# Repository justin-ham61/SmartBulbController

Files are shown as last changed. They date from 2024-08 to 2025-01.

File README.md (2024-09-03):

# SmartBulbController
SmartBulbController is an open-source input device built for the ESP32 microcontroller for controlling Smart Bulbs using the TP-Link Smart Home Protocol.

The goal of this project was to create a remote control device for Kasa Smart Lighting system within local network in order to eliminate the need for a smart phone app for lighting control.

# Dependencies
Several libraries are required for the device to work. 
- Adafruit_SSD1306 by Adafruit
- Adafruit_BusIO by Adafruit
- Adafruit_GFX_Library by Adafruit
- Ai_Esp32_Rotary_Encoder by Igor Antolic
- KasaSmartPlug updated by Justin Ham
    - Modified version of the [KasaSmartPlug](https://github.com/kj831ca/KasaSmartPlug?tab=readme-ov-file) library by Kris Jearakul to be compatible with Smart Bulbs and Smart Plugs.
- ArduinoJson by Benoit Blanchon

# Features
- Quick communication with light bulbs using the TP-Link Smart Home Protocol which is a TCP/IP Protocol that sends JSON payloads to devices. 
- Rotary Knob allows the control of brightness for multiple bulbs at the same time which is not available in the Kasa app.
- Built on FreeRTOS for efficient and responsive device interaction.
- OLED Display for bulb management and view of device states such as (On, Off, Error).

# FreeRTOS
- WiFi related tasks are managed using Semaphores and prohibits reliant tasks from running unless a connection is successfully made.
- User inputs are handled with ISR's that interact with RTOS queues.
- All tasks only operate when items are added to the queue and executes them promptly.
- Tasks notify lower priority tasks such as display task in order to update display.

# Designs

## Device Render
Device was designed with Fusion and prototype was printed using an Ender 3 Pro 3D Printer.

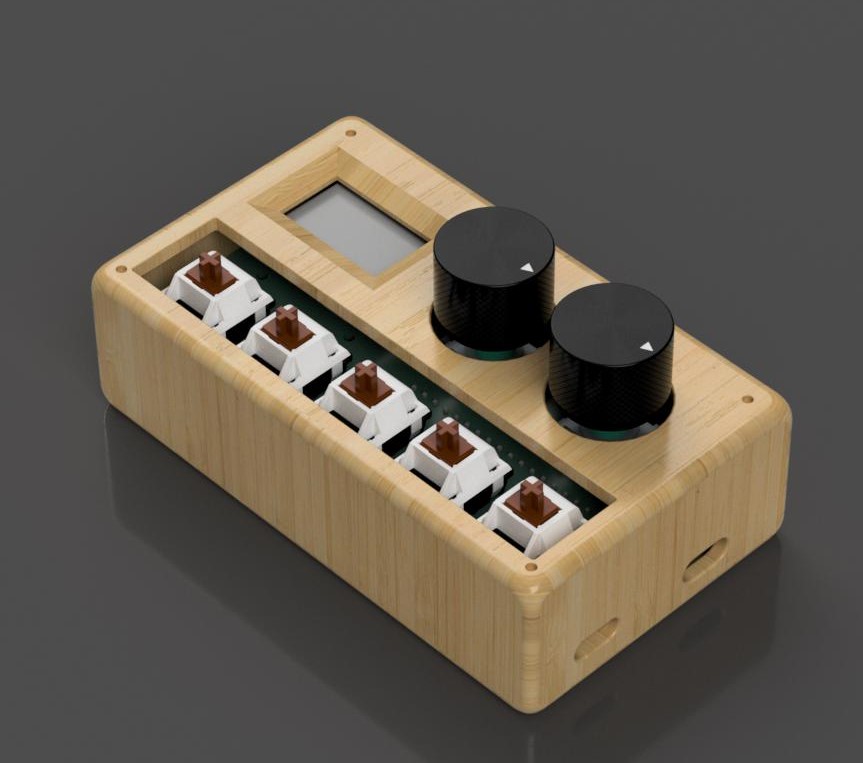
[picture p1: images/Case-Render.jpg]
Device Render


## First Working Prototype
First working prototype of the controller with a custom PCB and the 3D printed case.

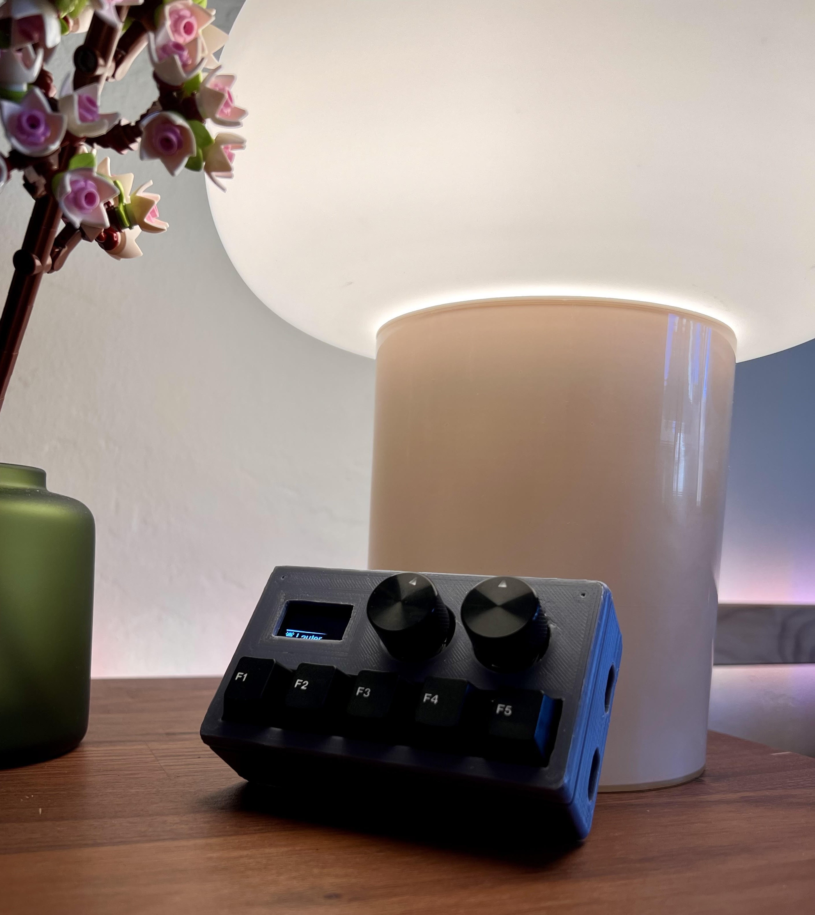
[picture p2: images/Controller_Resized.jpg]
Prototype Image


## OLED Display
- Menu
    - List of all bulbs and a dedicated "Reset" command for the ESP32 microcontroller. 
        - Although the firmware has auto update for dynamic IP assignment, it may have issue updating to the most recent IP address of the bulb.
        - The reset button can be used to restart the device and connect to the new IP.
- Bulbs show the current state of the bulb 
    - On
    - Off
    - Error (Exclamation icon)
- Changing the brightness will show the current brightness as a progress bar.

## Inputs
- 2 Rotary Encoders
    - 1 Encoder for menu navigation
    - 1 Encoder for On/Off and brightness control
- 5 Switches (MX Style)
    - Quick toggle for individual bulbs
    
## Control Options
User can control their light bulbs in several different ways

1. Use the quick use rotary encoder
    - Press encoder button to toggle On/Off for all bulbs
    - Rotate encoder knob to change the brightness for all bulbs
2. Quck individual bulb toggle
    - The 5 switches allow the users to quickly turn on and off individual bulbs
3. Menu Select toggle
    - Navigate and select desired bulb on the menu in order to toggle and change the brightness of a specific bulb.  

# Set Up Guide

1. Gather all materials listed in the parts document, you can order the PCB using the provided files or wire the device with a breadboard following the schematics. 
2. Prepare config file before flashing the device (Instruction shown below).
3. Once the device is put together, flash the device with the firmware and required libraries using the Arduino IDE.
4. Device set up will run automatically on initial start up. 
    - This step includes the device searching for bulbs as outlined in the config file on the local wifi network.
    - Having the device connected to a computer and reading the Serial output will help with any connectivity issues. 
    - Notes about better connection below
5. Once set up, all lightbulbs named in the config file should show up on the main menu.
6. The first 5 lights can be toggled with the 5 switches.

## Config File Instruction
In order to flash the ESP32 module with the firmware, the user must update the config file with some information.
- Home Wifi SSID (name) and Password
- Names of all light bulbs they want
    - Name must match the name set for the bulb during set up exactly.
- Total number of bulbs
~~~c++
#ifndef CONFIG_H
#define CONFIG_H

const char* SSID = "<User WiFi SSID>";
const char* PASSWORD = "<User WiFi Password>";

//List of all user bulb names
char* aliases[] = {
  "<User Bulb Name 1>",
  "<User Bulb Name 2>",
  "<User Bulb Name 3>"
};

//Total number of bulbs, needs to match the number of bulb names above.
const int size = 0;

//Time between inactivity and sleep
const int inactivity_time = 15000;

//Minimum and Maximum brightness
const int min_brightness = 0;
const int max_brightness = 100;

#endif
~~~~

On start up, the ESP32 will begin to look for bulbs that are active and add them to the device's list of bulbs if the name is included in the config file.

For best results, please turn the smart bulb on with a phone during the set up.

# Future Plans
- Light temperature and color control.
- Custom group creations to group certain bulbs with another.
- Better rotary knob control between menu and controlling bulbs.
- Compatibility with devices that require Kasa Authentication such as light strips.

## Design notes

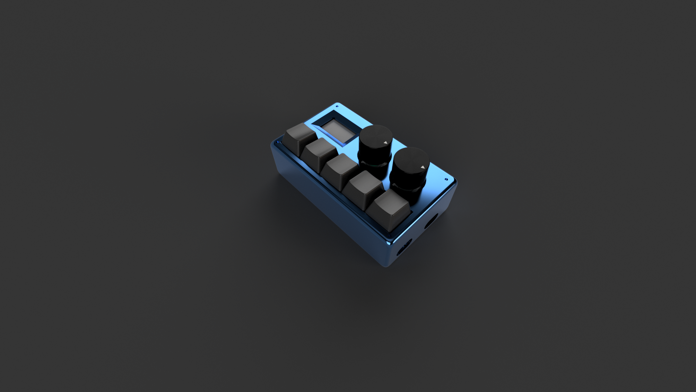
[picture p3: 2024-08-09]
images/Case.png

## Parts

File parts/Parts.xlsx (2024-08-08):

ESP32 | https://www.amazon.com/dp/B0718T232Z?psc=1&ref=ppx_yo2ov_dt_b_product_details
128 x 64 .96 Inch OLED Screen | https://www.amazon.com/dp/B0D46JPZHZ?psc=1&ref=ppx_yo2ov_dt_b_product_details
MX Style Switches | https://divinikey.com/products/cherry-mx2a-black-linear-switches?variant=41617139499073
EC11 Rotary Encoder | https://www.amazon.com/DIYhz-Rotary-Encoder-Digital-Potentiometer/dp/B07D3DF8TK
Rechargeable Lithium Battery | https://www.amazon.com/dp/B07CXNQ3ZR?psc=1&ref=ppx_yo2ov_dt_b_product_details
Charging Module (T4056) | https://www.amazon.com/dp/B07PKND8KG?psc=1&ref=ppx_yo2ov_dt_b_product_details
JST Cables | https://www.amazon.com/dp/B013JRWCBU?psc=1&ref=ppx_yo2ov_dt_b_product_details

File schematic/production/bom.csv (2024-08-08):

Designator | Footprint | Quantity | Value | LCSC Part #
R1, R2, R3, R4, R5, R6, R7 | 1206 | 7 | R_Small_US

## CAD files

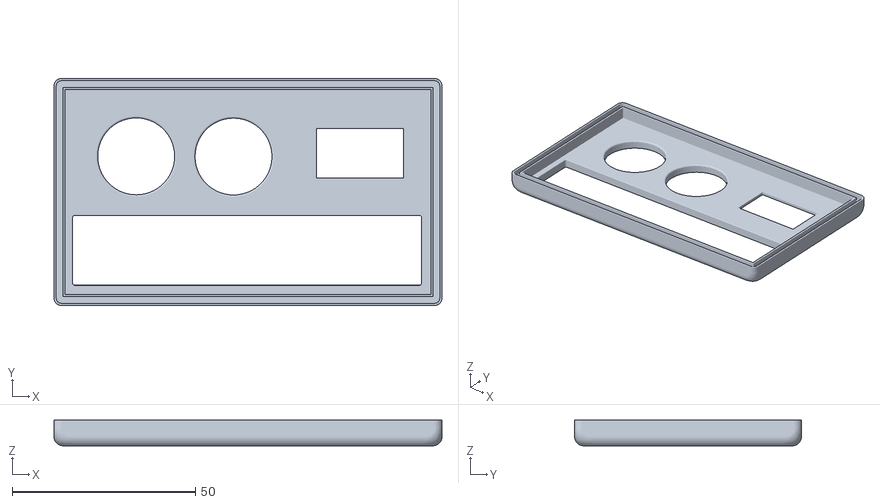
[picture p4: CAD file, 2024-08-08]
cad/Top.stl
106.0 x 62.0 x 7.00

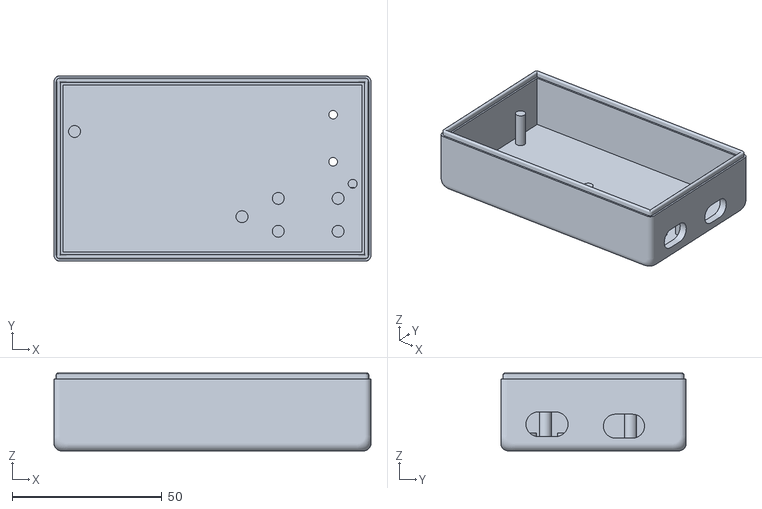
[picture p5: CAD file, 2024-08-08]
cad/Bottom.stl
106.0 x 62.0 x 26.0

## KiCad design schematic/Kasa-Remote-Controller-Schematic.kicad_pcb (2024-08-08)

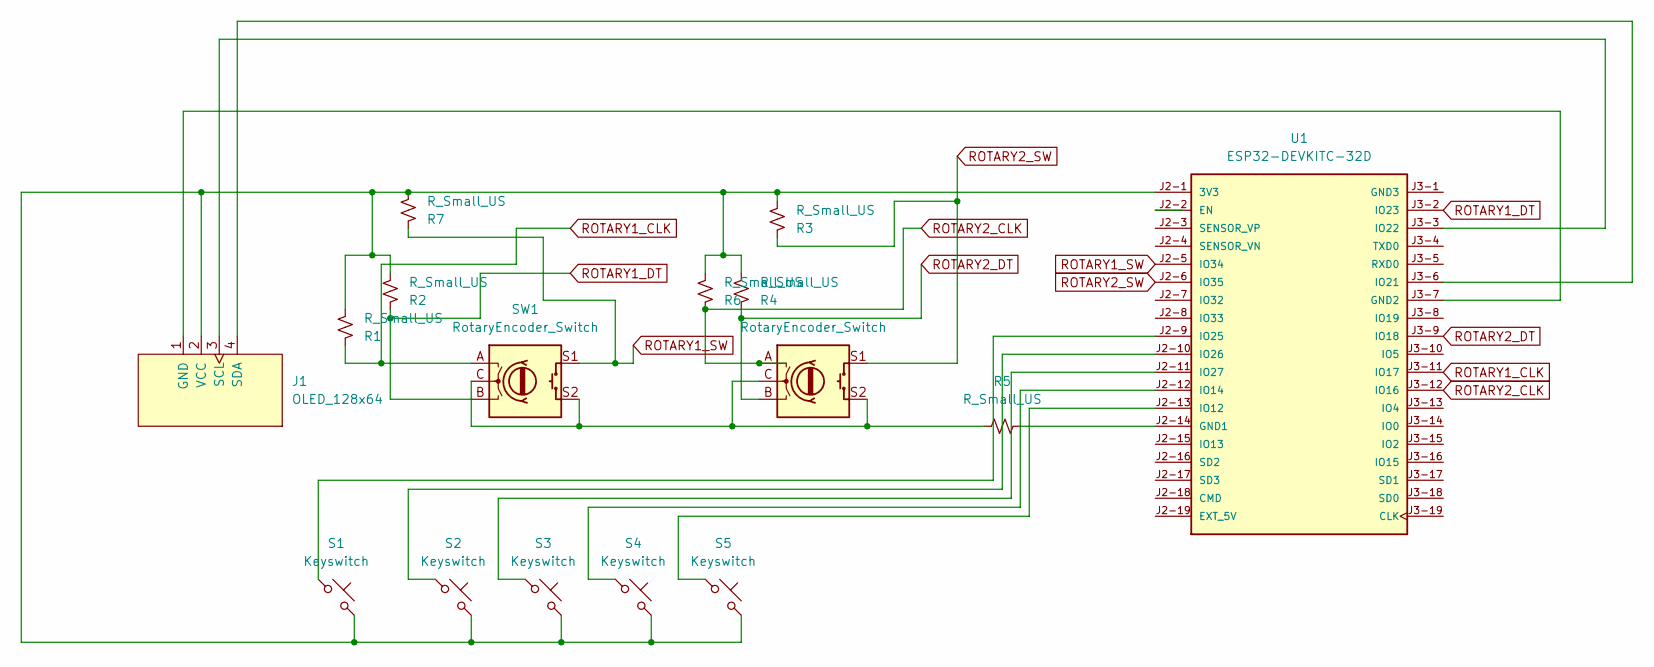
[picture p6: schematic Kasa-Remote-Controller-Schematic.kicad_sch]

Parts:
J1: OLED_128x64; MODULE_DM-OLED096-636
R1, R2, R3, R4, R5, R6, R7: R_Small_US; R_1206_3216Metric_Pad1.30x1.75mm_HandSolder
S1, S2, S3, S4, S5: Keyswitch; MX_PCB_1.00u
SW1, SW2: RotaryEncoder_Switch; RotaryEncoder_Alps_EC12E-Switch_Vertical_H20mm
U1: ESP32-DEVKITC-32D; MODULE_ESP32-DEVKITC-32D; PARTREV V4

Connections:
unnamed: J1.1 (GND), U1.J3-7 (GND2)
unnamed: J1.3 (SCL), U1.J3-3 (IO22)
unnamed: J1.4 (SDA), U1.J3-6 (IO21)
unnamed: J1.2 (VCC), R1.2, R2.2, R3.2, R4.2, R6.2, R7.2, S1.2, S2.2, S3.2, S4.2, S5.2, U1.J2-1 (3V3)
unnamed: R5.1, SW1.C, SW1.S2, SW2.C, SW2.S2
unnamed: R5.2, U1.J2-14 (GND1)
unnamed: S5.1, U1.J2-13 (IO12)
unnamed: S4.1, U1.J2-12 (IO14)
unnamed: S1.1, U1.J2-9 (IO25)
unnamed: S2.1, U1.J2-10 (IO26)
unnamed: S3.1, U1.J2-11 (IO27)
ROTARY1_CLK: R1.1, SW1.A, U1.J3-11 (IO17)
ROTARY1_DT: R2.1, SW1.B, U1.J3-2 (IO23)
ROTARY1_SW: R7.1, SW1.S1, U1.J2-5 (IO34)
ROTARY2_CLK: R6.1, SW2.A, U1.J3-12 (IO16)
ROTARY2_DT: R4.1, SW2.B, U1.J3-9 (IO18)
ROTARY2_SW: R3.1, SW2.S1, U1.J2-6 (IO35)

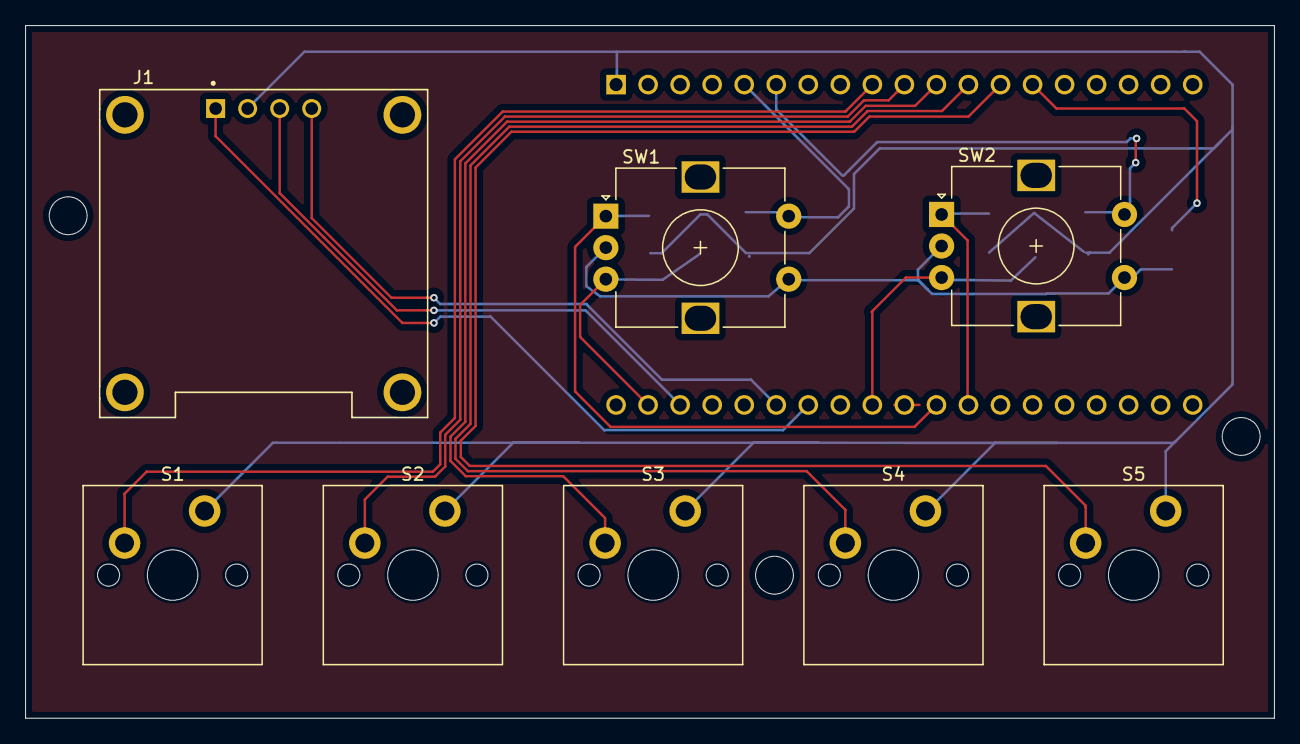
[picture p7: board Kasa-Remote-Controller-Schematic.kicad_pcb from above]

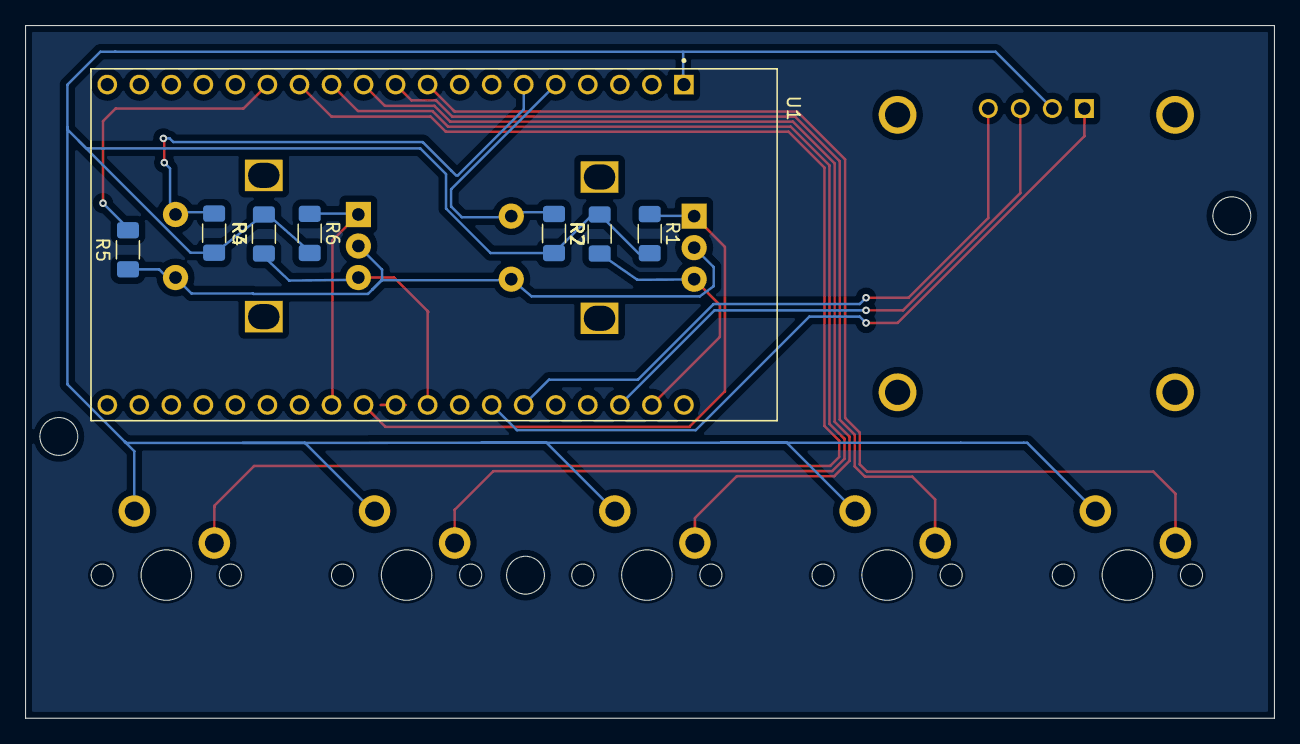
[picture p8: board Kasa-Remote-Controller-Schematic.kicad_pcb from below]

Board: 2 copper layers, 99.0 x 54.9 mm, 16 parts (8 on the bottom side), 17 nets.

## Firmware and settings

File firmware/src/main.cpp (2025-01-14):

#include <stdio.h>
#include "Arduino.h"
#include <WiFi.h>
#include "freertos/FreeRTOS.h"
#include "freertos/task.h"
#include "freertos/timers.h"
#include "driver/gpio.h"
#include "config.h"
#include "esp_sleep.h"
#include "typedef/command.h"
#include "typedef/menu_item.h"

#include "task_device_setup/task_device_setup.h"
#include "task_update_flash/task_update_flash.h"
#include "task_display/task_display.h"
#include "task_command/task_command.h"

// ------------------- Libraries ------------------------ //
#include <ArduinoJson.h>
#include <AiEsp32RotaryEncoder.h>
#include <AiEsp32RotaryEncoderNumberSelector.h>
#include <KasaSmartPlug.h>
#include <Adafruit_GFX.h>
#include <Adafruit_SSD1306.h>
#include <Wire.h>
#include <Fonts/FreeSans9pt7b.h>
#include <Fonts/FreeSansBold9pt7b.h>
#include <EEPROM.h>

#if CONFIG_FREERTOS_UNICORE
static const BaseType_t app_cpu = 0;
#else 
static const BaseType_t app_cpu = 1;
#endif

//Pin Set up
#include "pin_def.h"

AiEsp32RotaryEncoder *quick_rotary_encoder = new AiEsp32RotaryEncoder(QUICK_ROTARY_DT, QUICK_ROTARY_CLK, QUICK_ROTARY_SW, VCC_PIN, ROTARY_ENCODER_STEPS);
AiEsp32RotaryEncoderNumberSelector quick_number_selector = AiEsp32RotaryEncoderNumberSelector();
AiEsp32RotaryEncoder menu_rotary_encoder = AiEsp32RotaryEncoder(MENU_ROTARY_DT, MENU_ROTARY_CLK, MENU_ROTARY_SW, VCC_PIN, ROTARY_ENCODER_STEPS);

//Queue Set up
static const uint8_t max_command_queue_len = 10;
QueueHandle_t command_queue;

static const uint8_t max_toggle_queue_len = 5;
QueueHandle_t toggle_queue;

static const uint8_t max_brightness_queue_len = 5;
QueueHandle_t brightness_queue;

static const uint8_t max_color_queue_len = 5;
QueueHandle_t color_queue;


static const uint8_t max_menu_display_queue_len = 5;
static QueueHandle_t menu_display_queue;

//Debounce and Button Queue Timers
TimerHandle_t xTimer;
TimerHandle_t xQuickRotaryTimer;
TimerHandle_t xModeSwitchTimer;
TimerHandle_t xMenuRotarySwitchTimer;
TimerHandle_t xQuickRotarySwitchTimer;

//Button Flag
volatile uint8_t button_state_flag;


//Task Handles
static TaskHandle_t command_read_task_handle = NULL;
TaskHandle_t display_task_handle = NULL;
static TaskHandle_t wifi_task_handle = NULL;
static TaskHandle_t device_discover_task_handle = NULL;
static TaskHandle_t toggle_bulb_task_handle = NULL;
static TaskHandle_t quick_rotary_task_handle = NULL;
static TaskHandle_t brightness_task_handle = NULL;
static TaskHandle_t menu_rotary_task_handle = NULL;
static TaskHandle_t brightness_display_task_handle = NULL;
static TaskHandle_t color_task_handle = NULL;
static TaskHandle_t update_flash_task_handle = NULL;

//Sleep Handles
TimerHandle_t xIdleTimer;
esp_sleep_source_t wakeup_source; 

//Wifi Dependancies
SemaphoreHandle_t wifiSemaphore;

//Bulbs
KASAUtil kasaUtil;

int numberOfBulbs;
bool all_state = false;
int size = sizeof(aliases)/sizeof(aliases[0]);


//DeviceMode
uint8_t device_mode = 0b00000001;

//Display config
#define OLED_ADDR 0x3C
Adafruit_SSD1306 display(128, 64, &Wire, -1);
menu_item menuItems[15];


//Task Params
int all_brightness = 0;

IRAM_ATTR void buttonHandle1(){
    if(button_state_flag & 1){
        return;
    } else {
        button_state_flag |= 1;
        xTimerStart(xTimer, 0);
    }
}
IRAM_ATTR void buttonHandle2(){
    if(button_state_flag & 2){
        return;
    } else {
        button_state_flag |= 2;
        xTimerStart(xTimer, 0);
    }
}
IRAM_ATTR void buttonHandle3(){
    if(button_state_flag & 4){
        return;
    } else {
        button_state_flag |= 4;
        if(xTimerStartFromISR(xTimer, 0) != pdPASS){
            return;
        }
    }
}
IRAM_ATTR void buttonHandle4(){
    if(button_state_flag & 8){
        return;
    } else {
        button_state_flag |= 8;
        if(xTimerStartFromISR(xTimer, 0) != pdPASS){
            return;
        }
    }
}
IRAM_ATTR void buttonHandle5(){
    if(button_state_flag & 16){
        return;
    } else {
        button_state_flag |= 16;
        if(xTimerStartFromISR(xTimer, 0) != pdPASS){
            return;
        }
    }
}
IRAM_ATTR void readEncoderISRQuick(){
    quick_rotary_encoder->readEncoder_ISR();
    xTimerStartFromISR(xQuickRotaryTimer, 0);
    xTimerStartFromISR(xIdleTimer, 0);
    xTimerStartFromISR(xModeSwitchTimer, 0);
    xTaskNotifyGive(brightness_display_task_handle);
}

IRAM_ATTR void readEncoderISRMenu(){
    menu_rotary_encoder.readEncoder_ISR();
    if(device_mode & 1){
        xTaskNotifyGive(display_task_handle);
        xTimerStartFromISR(xIdleTimer, 0);
    }

}

IRAM_ATTR void menuRotaryHandle(){
    xTimerStart(xMenuRotarySwitchTimer, 0);
    xTimerStartFromISR(xIdleTimer, 0);
}

IRAM_ATTR void quickRotaryHandle(){
    xTimerStart(xQuickRotarySwitchTimer, 0);
    xTimerStartFromISR(xIdleTimer, 0);
}

// Handles buttons based on current context and adds the command to the queue
// Button presses should get translated to toggle or color based on what the current mode is 
void vButtonTimerCallback(TimerHandle_t xTimer){
    command new_command; 
    if(device_mode & 1){
        for(int i = 0; i < numberOfBulbs; i++){
            uint8_t curr_bitmask = 1 << i;
            if (button_state_flag & curr_bitmask){
                button_state_flag &= ~(1 << i);
                KASADevice* dev = kasaUtil.GetSmartPlugByIndex(i);
                new_command.value = dev->state;
                new_command.index = i;
                new_command.task = 0;
                if(xQueueSend(command_queue, (void *)&new_command, 10) != pdTRUE){
                    Serial.println("Queue Full");
                }
            }
        }
    } else if (device_mode & 4){
        new_command.task = 3;
        new_command.index = menu_rotary_encoder.readEncoder();
        for(int i = 0; i < 5; i++){
            uint8_t curr_bitmask = 1 << i;
            if(button_state_flag & curr_bitmask){
                button_state_flag &= ~curr_bitmask;
                new_command.value = i;
            }
        }
        if(xQueueSend(command_queue, (void *)&new_command, 10) != pdTRUE){
            Serial.println("Queue Full");
        }
        //Insert code for sending color change commands
    }
    if(xTimerStart(xIdleTimer, portMAX_DELAY) != pdTRUE){
        Serial.println("Failed to start idle timer");
    }
}

void vIdleTimerCallback(TimerHandle_t xIdleTimer){
    Serial.println("Waiting for semaphore for idle");
    //Awaits tasks that depend on wifi to finish before going to sleep
    xSemaphoreTake(wifiSemaphore, portMAX_DELAY);
    Serial.println("Disconnected WiFi and going to sleep");
    WiFi.disconnect();

    gpio_wakeup_enable(GPIO_NUM_12, GPIO_INTR_HIGH_LEVEL);
    esp_sleep_enable_gpio_wakeup();

    display.clearDisplay();
    display.display();


    vTaskDelay(100/portTICK_PERIOD_MS);
    esp_light_sleep_start();
    vTaskDelay(200/portTICK_PERIOD_MS);

    xTimerStart(xIdleTimer, 0);
    gpio_wakeup_disable(GPIO_NUM_12);
    xTaskNotifyGive(display_task_handle);
    WiFi.reconnect();
}

void vQuickRotaryCallback(TimerHandle_t xQuickRotaryTimer){
    command new_command;
    new_command.task = 1;
    new_command.value = quick_number_selector.getValue();
    if(device_mode & 1){
        for(int i = 0; i < numberOfBulbs; i++){
            new_command.index = i;
            if(xQueueSend(command_queue, (void *)&new_command, 10) != pdTRUE){
                Serial.println("Queue is Full");
            }
        }
    } else if (device_mode & 4){
        Serial.println("Sending");
        new_command.index = menu_rotary_encoder.readEncoder();
        if(xQueueSend(command_queue, (void *)&new_command, 10) != pdTRUE){
            Serial.println("Queue is Full");
        }
    }
}

void vModeSwitchCallback(TimerHandle_t xModeSwitchTimer){
    device_mode = 1;
    xTaskNotifyGive(display_task_handle);
}

void vMenuSwitchCallback(TimerHandle_t xMenuRotarySwitchTimer){
    int menu_index = menu_rotary_encoder.readEncoder();
    int curr_type = menuItems[menu_index].type;

    //Handles if button press is trying to select a bulb
    if(curr_type == 0){
        device_mode = 4;
        xTaskNotifyGive(brightness_display_task_handle);
        xTimerStart(xModeSwitchTimer, 0);
    //Handles if button press is activating a preset
    } else if (curr_type == 1){
        command color_command;
        color_command.task = 3;
        color_command.value = menu_index - numberOfBulbs;
        for(int i = 0; i < numberOfBulbs; i++){
            color_command.index = i;
            if(xQueueSend(command_queue, (void *)&color_command, 10) != pdTRUE){
                Serial.println("Queue Full");
            }
        }
    //Handles if button press is resetting device
    } else if (curr_type == 2){
        Serial.println("reset");
        esp_restart();
    //Handles if button press is saving bulb configuration
    } else if (curr_type == 3){
        Serial.println("Save");
        xTaskNotifyGive(update_flash_task_handle);
    }

    xTimerStart(xIdleTimer, 0);
}

void vQuickSwitchCallback(TimerHandle_t xQuickRotarySwitchTimer){
    command new_command;
    new_command.task = 0;
    new_command.value = all_state;
    for(int i = 0; i < numberOfBulbs; i++){
        new_command.index = i;
        if(xQueueSend(command_queue, (void *)&new_command, 10) != pdTRUE){
            Serial.println("Queue is Full");
        }
    }
    all_state = !all_state;
}

void WiFiEvent(WiFiEvent_t event){
    switch(event){
        case SYSTEM_EVENT_STA_GOT_IP:
            Serial.println("WiFi Connected");
            Serial.print("IP Address: ");
            Serial.println(WiFi.localIP());
            xSemaphoreGive(wifiSemaphore);
            break;
        case SYSTEM_EVENT_STA_DISCONNECTED:
            xSemaphoreTake(wifiSemaphore, 0);
            Serial.println("Attempting to reconnect");
            WiFi.reconnect();
            break;
        default:
            break;
    }
}

void connectToWifi(void *parameter){
    while(1){
        WiFi.disconnect(true);

        xSemaphoreTake(wifiSemaphore, portMAX_DELAY);

        vTaskDelay(500/portTICK_PERIOD_MS);

        WiFi.onEvent(WiFiEvent);

        WifiParameters_t *wifi_params = (WifiParameters_t *)parameter;
        WiFi.begin(wifi_params->SSID, wifi_params->PASSWORD);
        while(WiFi.status() != WL_CONNECTED){
            delay(500);
            Serial.println(".");
        }
        
        Serial.println("Connected to the WiFi network");
        vTaskDelete(NULL); 
    }
}


void setup() {
    Serial.begin(115200);
    vTaskDelay(200/portTICK_PERIOD_MS);

    // ------------------------------------ WIFI TASK INIT ------------------------------------------ //
    if (!EEPROM.begin(256)) {
        Serial.println("Failed to initialise EEPROM");
        return;
    }


    wifiSemaphore = xSemaphoreCreateBinary();
    if(wifiSemaphore == NULL){
        Serial.println("Unable to create wifi semaphore");
        while(1);
    } else {
        xSemaphoreGive(wifiSemaphore);
    }

    xTaskCreate(
        connectToWifi, 
        "Wifi Task",
        4096,
        &wifi_params, 
        4,
        &wifi_task_handle
    );

    display.begin(SSD1306_SWITCHCAPVCC, OLED_ADDR);
    display.setTextColor(WHITE);
    display.setTextSize(1);
    display.setFont();
    display.display(); // Display the message
    display.clearDisplay();
    // ------------------------------------ KASA BULB INIT ------------------------------------------ //
    xTaskCreate(
        vAddDeviceTask,
        "Device Task",
        6000,
        NULL,
        3,
        &device_discover_task_handle
    );

    //Command Queue Intialization
    command_queue = xQueueCreate(max_command_queue_len, sizeof(command));
    toggle_queue = xQueueCreate(max_toggle_queue_len, sizeof(command));
    brightness_queue = xQueueCreate(max_brightness_queue_len, sizeof(command));
    color_queue = xQueueCreate(max_color_queue_len, sizeof(command));
    menu_display_queue = xQueueCreate(max_menu_display_queue_len, sizeof(int));


    // ------------------------------------ TIMER INIT ------------------------------------------ //
    //Debounce & Button Timer 
    xTimer = xTimerCreate(
        "Debounce Timer",
        pdMS_TO_TICKS(200),
        pdFALSE,
        (void *)0,
        vButtonTimerCallback
    );
    if(xTimer == NULL){
        Serial.println("Was not able to initialize a debounce timer");
    }

    //Sleep timer
    xIdleTimer = xTimerCreate(
        "Idle Timer",
        pdMS_TO_TICKS(15000),
        pdFALSE,
        (void *)0,
        vIdleTimerCallback
    );
    if(xIdleTimer == NULL){
        Serial.println("Was not able to initialize idle timer");
    }

    //Rotary Timer
    xQuickRotaryTimer = xTimerCreate(
        "Quick Rotary Timer",
        pdMS_TO_TICKS(1000),
        pdFALSE,
        (void *)0,
        vQuickRotaryCallback
    );
    if(xQuickRotaryTimer == NULL){
        Serial.println("Was not able to initialize quick rotary timer");
    }

    //Display Mode Switch Timer
    xModeSwitchTimer = xTimerCreate(
        "Mode Switch Timer",
        pdMS_TO_TICKS(3000),
        pdFALSE,
        (void *)0,
        vModeSwitchCallback
    );

    xMenuRotarySwitchTimer = xTimerCreate(
        "Menu Switch Timer",
        pdMS_TO_TICKS(50),
        pdFALSE,
        (void *)0,
        vMenuSwitchCallback
    );

    xQuickRotarySwitchTimer = xTimerCreate(
    "Quick Switch Timer",
        pdMS_TO_TICKS(50),
        pdFALSE,
        (void *)0,
        vQuickSwitchCallback
    );

    
    // ------------------------------------ RUNTIME TASK INIT ------------------------------------------ //
    //Command Read Task Initialization
    xTaskCreate(
        vReadCommandTask, 
        "Command Task",
        2048,
        NULL, 
        2,
        &command_read_task_handle
    );

    xTaskCreate(
        vToggleTask,
        "Toggle Task", 
        2048, 
        NULL,
        2,
        &toggle_bulb_task_handle
    );

    xTaskCreate(
        vBrightnessTask,
        "Brightness Task",
        2048,
        NULL,
        2,
        &brightness_task_handle
    );

    xTaskCreate(
        vColorTask,
        "Color Task",
        2048,
        NULL,
        2,
        &color_task_handle
    );
    
    //Rotary Encoder Set up
    quick_rotary_encoder->begin();
    quick_rotary_encoder->setup(readEncoderISRQuick);
    quick_number_selector.attachEncoder(quick_rotary_encoder);
    quick_number_selector.setRange(0, 99, 5, false, 0);
    quick_number_selector.setValue(50);
    quick_rotary_encoder->disableAcceleration();

    menu_rotary_encoder.begin();
    menu_rotary_encoder.setup(readEncoderISRMenu);
    menu_rotary_encoder.setBoundaries(0,size + 9,true);
    menu_rotary_encoder.disableAcceleration();

    xTaskCreate(
        vMenuDisplayTask,
        "Menu Display Task",
        4096,
        NULL,
        1,
        &display_task_handle
    );

    xTaskCreate(
        vBrightnessDisplayTask,
        "Brightness Display Task",
        4096,
        &all_brightness,
        1,
        &brightness_display_task_handle
    );

    xTaskCreate(
        vTaskUpdateFlash,
        "Update Flash",
        4096,
        NULL, 
        1, 
        &update_flash_task_handle
    );

    // ------------------------------------ GPIO INIT ------------------------------------------ //
    //Pin initialization for buttons
    pinMode(SW_1_PIN, INPUT_PULLDOWN);
    pinMode(SW_2_PIN, INPUT_PULLDOWN);
    pinMode(SW_3_PIN, INPUT_PULLDOWN);
    pinMode(SW_4_PIN, INPUT_PULLDOWN);
    pinMode(SW_5_PIN, INPUT_PULLDOWN);

    attachInterrupt(digitalPinToInterrupt(SW_1_PIN), buttonHandle1, RISING);
    attachInterrupt(digitalPinToInterrupt(SW_2_PIN), buttonHandle2, RISING);
    attachInterrupt(digitalPinToInterrupt(SW_3_PIN), buttonHandle3, RISING);
    attachInterrupt(digitalPinToInterrupt(SW_4_PIN), buttonHandle4, RISING);
    attachInterrupt(digitalPinToInterrupt(SW_5_PIN), buttonHandle5, RISING);

    pinMode(MENU_ROTARY_SW, INPUT_PULLDOWN);
    pinMode(QUICK_ROTARY_SW, INPUT_PULLDOWN);
    attachInterrupt(digitalPinToInterrupt(QUICK_ROTARY_SW), quickRotaryHandle, RISING);
    attachInterrupt(digitalPinToInterrupt(MENU_ROTARY_SW), menuRotaryHandle, RISING);


    //Pin set up for sleep wake up
    xTimerStart(xIdleTimer, portMAX_DELAY);
}

void loop(){

}

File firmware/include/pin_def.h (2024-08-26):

#ifndef PIN_CONFIG_H
#define PIN_CONFIG_H

#define LED_PIN GPIO_NUM_2
#define MENU_ROTARY_DT 23
#define MENU_ROTARY_CLK 17
#define MENU_ROTARY_SW 34
#define QUICK_ROTARY_DT 18
#define QUICK_ROTARY_CLK 16
#define QUICK_ROTARY_SW 35
#define VCC_PIN -1
#define ROTARY_ENCODER_STEPS 4
#define WAKE_SW GPIO_NUM_34
#define WAKE_SW_BITMASK 0xE005000
#define SW_1_PIN 25
#define SW_2_PIN 26
#define SW_3_PIN 27
#define SW_4_PIN 14
#define SW_5_PIN 12

#endif

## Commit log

2024-08-08 First commit of version 1 files
    [Bottom.stl, Kasa-Remote-Controller-Schematic.kicad_pcb, Kasa-Remote-Controller-Schematic.kicad_sch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]
2024-08-08 Add parts spreadsheet
    [Parts.xlsx]
2024-08-12 Update README.md to have prototype image
2024-08-14 Update button state with bit operation and change button_loop to event driven loop
